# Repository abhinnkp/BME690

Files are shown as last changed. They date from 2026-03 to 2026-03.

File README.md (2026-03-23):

# BME690 Sensor Module

## Overview

The **BME690 Sensor Module** is an environmental sensing board designed for accurate measurement of atmospheric parameters. It communicates via the **I2C protocol** and supports both **3.3V and 5V operation**, making it suitable for a wide range of embedded and IoT applications.

---

PCB Design File is in KiCAD

---

## Features

* Supports **I2C communication**
* Configurable **I2C address selection**
* Operates on **3.3V and 5V supply**
* Onboard **voltage regulation (5V → 3.3V)**
* Integrated **level shifting for I2C lines**
* Built-in **ESD protection**

---

## Hardware Details

### 1. Power Supply

* The module can be powered using:

  * **3.3V (direct)**
  * **5V input**
* **AP2112K-3.3** LDO regulator is used to convert 5V to 3.3V for the sensor.

---

### 2. I2C Communication

* Communication interface: **I2C**
* Compatible with most microcontrollers (ESP32, STM32, Arduino, etc.)

---

### 3. I2C Address Configuration

The module provides flexible address selection using resistors:

| Resistor Configuration | I2C Address |
| --- | --- |
| R6 = 4.7KΩ | `0x77` |
| R7 = 0Ω (0E) | `0x76` |

> Note: Populate only one resistor at a time for correct address selection.

---

### 4. Level Shifting

* **BSS138 MOSFETs** are used for bidirectional level shifting
* Ensures safe communication between:

  * 5V logic systems
  * 3.3V sensor

---

### 5. ESD Protection

* **TPD2E2U06DRLR** is used to protect I2C lines from electrostatic discharge (ESD)

---

## Pin Configuration

| Pin Name | Description |
| --- | --- |
| VCC | 3.3V / 5V Input |
| GND | Ground |
| SDA | I2C Data Line |
| SCL | I2C Clock Line  |

---

## Typical Connection Diagram

```
MCU            BME690 Module
----           --------------
VCC   -------> VCC
GND   -------> GND
SDA   -------> SDA
SCL   -------> SCL
```

---

## Applications

* Environmental monitoring
* Smart home systems
* Industrial IoT
* Weather stations
* Air quality monitoring

---

## Notes

* Ensure correct **I2C address selection** before powering the module
* Do not populate both R6 and R7 simultaneously
* Use proper pull-up resistors if required (typically already present on board)

---

## License

This project is open-source. Feel free to use and modify as per your requirements.

---

## Author

Developed for embedded and IoT applications.

---

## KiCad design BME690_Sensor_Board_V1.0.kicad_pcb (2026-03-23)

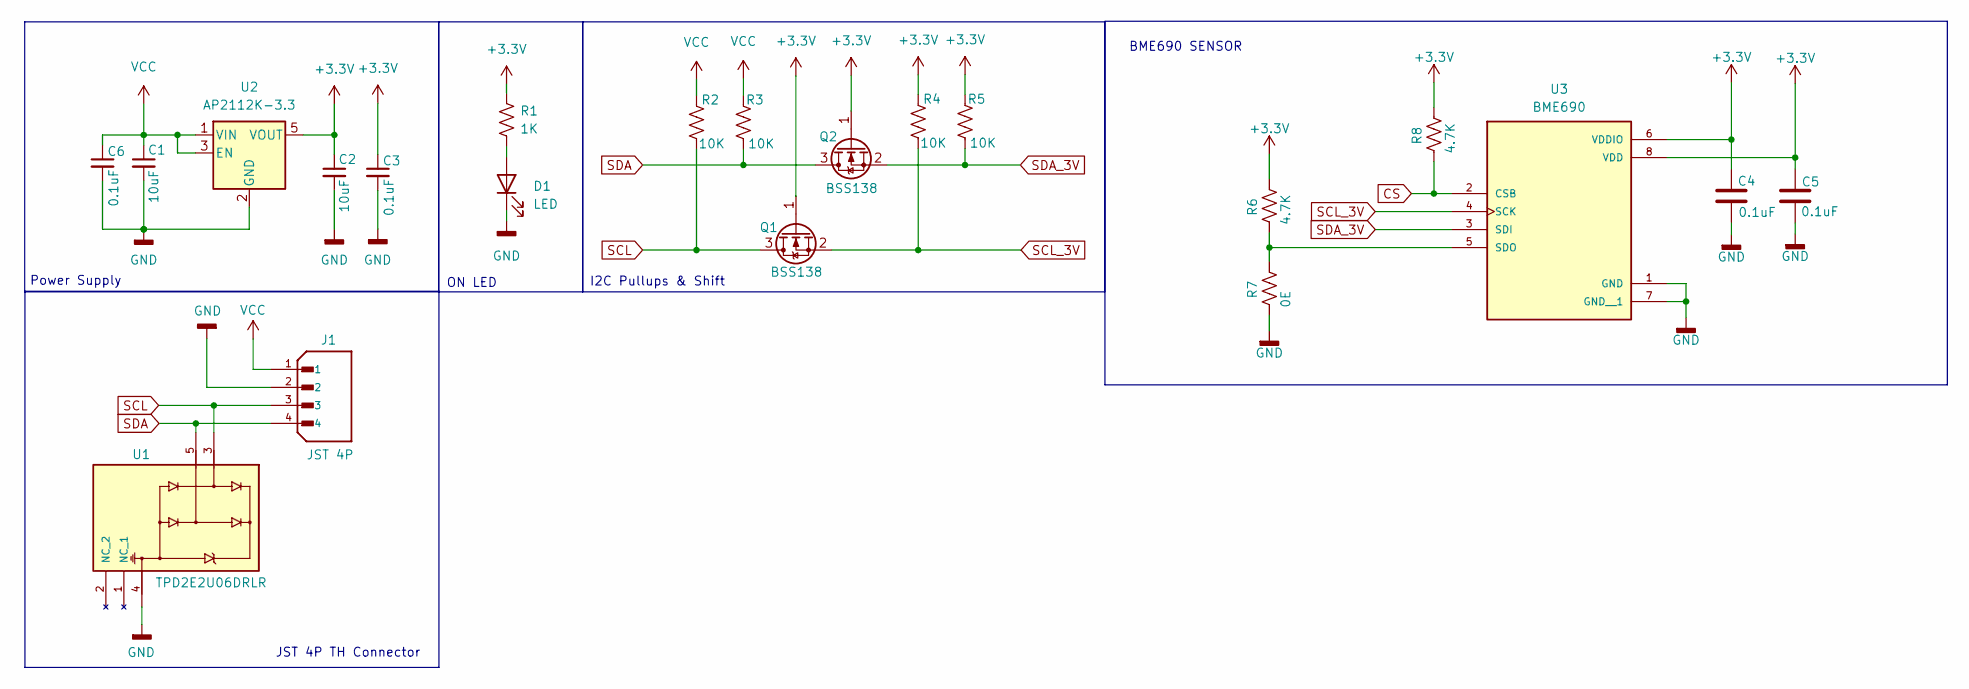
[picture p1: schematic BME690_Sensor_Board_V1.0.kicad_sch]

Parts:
C1, C2: 10uF; C_0603_1608Metric_Pad1.08x0.95mm_HandSolder
C3, C4, C5, C6: 0.1uF; C_0603_1608Metric_Pad1.08x0.95mm_HandSolder
D1: LED; LED_0805_2012Metric
J1: JST 4P; JST_S4B-PH-SM4-TB; PARTREV 7/4/21
Q1, Q2: BSS138; SOT-23
R1: 1K; R_0603_1608Metric_Pad0.98x0.95mm_HandSolder
R2, R3, R4, R5: 10K; R_0603_1608Metric_Pad0.98x0.95mm_HandSolder
R6, R8: 4.7K; R_0603_1608Metric_Pad0.98x0.95mm_HandSolder
R7: 0E; R_0603_1608Metric_Pad0.98x0.95mm_HandSolder
U1: TPD2E2U06DRLR; SOTFL50P160X60-5N
U2: AP2112K-3.3; SOT-23-5
U3: BME690; BME690_FP; PARTREV 1.9

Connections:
+3.3V: C2.1, C3.1, C4.1, C5.1, Q1.1 (G), Q2.1 (G), R1.1, R4.1, R5.1, R6.1, R8.1, U2.5 (VOUT), U3.6 (VDDIO), U3.8 (VDD)
CS: R8.2, U3.2 (CSB)
GND: C1.2, C2.2, C3.2, C4.2, C5.2, C6.2, D1.1 (K), J1.2, R7.2, U1.4, U2.2 (GND), U3.1 (GND), U3.7 (GND__1)
unnamed: D1.2 (A), R1.2
unnamed: R6.2, R7.1, U3.5 (SDO)
SCL: J1.3, Q1.3 (D), R2.2, U1.3
SCL_3V: Q1.2 (S), R4.2, U3.4 (SCK)
SDA: J1.4, Q2.3 (D), R3.2, U1.5
SDA_3V: Q2.2 (S), R5.2, U3.3 (SDI)
VCC: C1.1, C6.1, J1.1, R2.1, R3.1, U2.1 (VIN), U2.3 (EN)

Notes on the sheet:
JST 4P TH Connector
Power Supply
ON LED
BME690 SENSOR
I2C Pullups & Shift

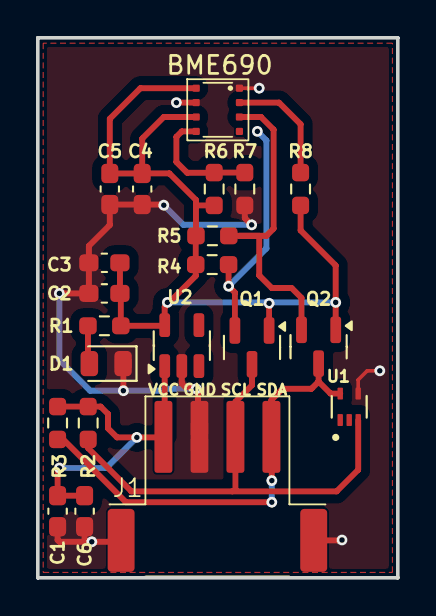
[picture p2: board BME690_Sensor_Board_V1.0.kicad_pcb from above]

Board: 2 copper layers, 20.0 x 30.0 mm, 21 parts (0 on the bottom side), 10 nets.
